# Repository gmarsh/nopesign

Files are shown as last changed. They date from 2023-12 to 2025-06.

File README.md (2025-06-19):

## NOPE sign design files  

**All files are (c) 2025, Gary Marsh (gmarsh @ github)
Released under a CC BY-SA V4.0 license.**

All files here are old, poorly organized and unsupported. Use at your own risk :)

You'll need the following tools:
 
- Microcontroller code:
-- STM32CubeIDE for editing/compiling the source code
-- STM32CubeProg for programming the sign over USB DFU
-- Both of the above are available free from ST Microelectronics (http://www.st.com)
- Schematic and PCB design: Kicad (http://www.kicad.org)
- 3D design: OpenSCAD (http://openscad.org)

Directory contents:
- /3d_design/ = STL files for sign
- /3d_design/openscad = OpenSCAD source code for generating the STL files. The code also generates a few SVG files (board outline, etc) to be used in Kicad.
- /kicad/ = Kicad project for the sign electronics
- /kicad/gerbers/ = Gerber files ready to order
- /kicad/production/ = JLCPCB files needed to do a production run. Not all parts are guaranteed to be in stock.
- /software/ = Source code for the STM32 microcontroller.

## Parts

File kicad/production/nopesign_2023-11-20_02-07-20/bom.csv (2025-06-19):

Designator | Footprint | Quantity | Value | LCSC Part #
C1, C10, C11, C12, C13, C14, C15, C16, C17, C18, C19, C2, C20, C21, C22, C23, C24, C25, C26, C27, C28, C29, C3, C30, C34, C35, C37, C38, C39, C4, C40, C41, C42, C43, C44, C45, C46, C47, C48, C49, C5, C50, C51, C52, C53, C54, C55, C56, C57, C58, C59, C6, C60, C61, C62, C63, C64, C65, C66, C67, C68, C69, C7, C70, C71, C8, C9 | 0603 | 67 | 0.1u | C14663
C31, C32, C33 | 0603 | 3 | 1000p | C1588
C36, C72 | 0805 | 2 | 1u | C28323
D1, D10, D11, D12, D13, D14, D15, D16, D17, D18, D19, D2, D20, D21, D22, D23, D24, D25, D26, D27, D28, D29, D3, D30, D31, D32, D33, D34, D35, D36, D37, D38, D39, D4, D40, D41, D42, D43, D44, D45, D46, D47, D48, D49, D5, D50, D51, D52, D53, D54, D55, D56, D57, D58, D59, D6, D60, D61, D62, D63, D64, D65, D7, D8, D9 | LED_WS2812B_PLCC4_5.0x5.0mm_P3.2mm | 65 | WS2812B | C2843785
FB1 | 0805 | 1 | 100Z | C1015
J1 | USB_C_Receptacle_HRO_TYPE-C-31-M-12 | 1 | USB_C_Receptacle_USB2.0 | C165948
R1 | 0603 | 1 | 1M | C22935
R2, R3 | 0603 | 2 | 5.1k | C23186
SW1 | SW_Tactile_SPST_Angled_PTS645Vx83-2LFS | 1 | DIM | C285530
SW2 | SW_Tactile_SPST_Angled_PTS645Vx83-2LFS | 1 | COLOR | C285530
SW3 | SW_Tactile_SPST_Angled_PTS645Vx83-2LFS | 1 | MODE | C285530
U1 | TSSOP-20_4.4x6.5mm_P0.65mm | 1 | STM32F042F6Px | C2969989
U2 | SOT-23-3 | 1 | XC6206PxxxMR | C5446
U3 | SOT-353_SC-70-5 | 1 | 74AHCT1G125 | C151417

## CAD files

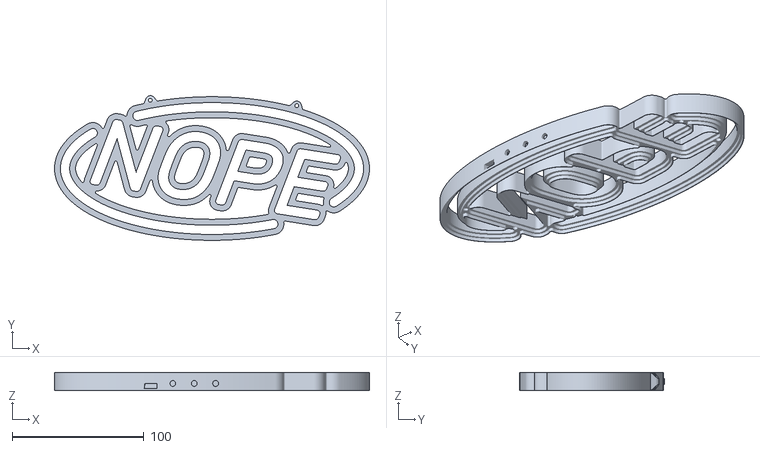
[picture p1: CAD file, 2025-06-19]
3D_design/nopesign_frame.stl
239.0 x 109.8 x 14.0

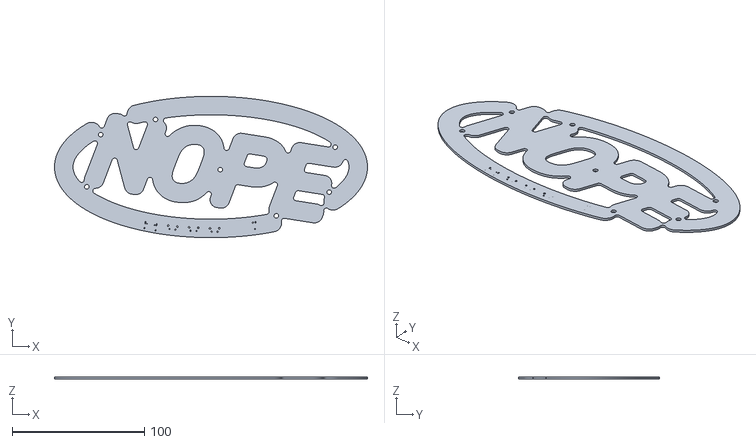
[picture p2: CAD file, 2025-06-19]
3D_design/openscad/nope_pcb.stl
237.0 x 107.0 x 1.58

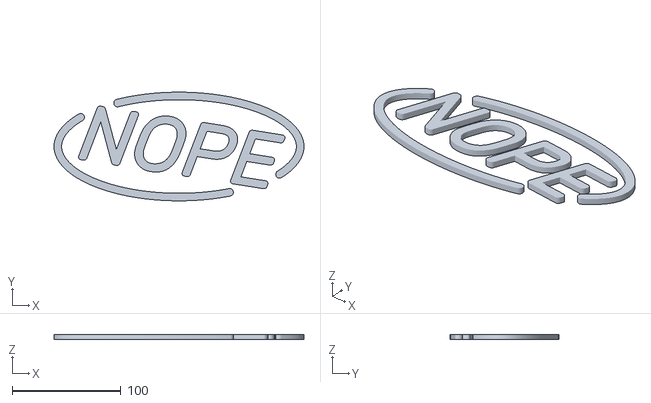
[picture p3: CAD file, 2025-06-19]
3D_design/nopesign_logo.stl
230.0 x 100.0 x 4.80

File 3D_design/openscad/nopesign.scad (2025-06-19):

/* 

nope sign SCAD file
(c) 2025, Gary Marsh, github.com/gmarsh
CC BY-SA V4.0 license

This code is a mess, but hopefully decipherable. Feel free to clean it up and throw it back at the github if you hate it.

Workflow for making a new sign:

(1) Make logo_2d() point at a SVG for a new logo.
(2) preview quick_preview_3d(), you'll probably need to mess with the positive/negative offsets in frame_2d() for a good looking outline.
(3) preview pcb_2d() and make sure it looks sane, then export it as a SVG. This is the PCB outline you want.
(4) Pull the SVG into Inkscape, disable fills, save it again as a SVG and import it into Kicad as the board outline layer.
(5) Do the same process for pcb_part_clearance_2d() and logo_2d() and bring those into Kicad on reference layers to guide part placement. 
(6) Do electronics nerd shit
(7) Export STEP files from Kicad for the PCB and parts, convert these to STLs, then update pcb_preview() to point at these files.
(8) Come up with all new cutouts in frame_3d() for buttons and switches and everything else. Confirm no interference by intersection()-ing pcb_preview() and frame_3d()/logo_3d().
(9) Once everything looks good, print frame_3d() and logo_3d() together to make your sign.

*/

// MAIN OUTPUTS

// uncomment for the frame (black plastic) part
color("#3F3F3F") frame_3d();
// uncomment for the logo (clear/opaque plastic) part
color("cyan",0.3) logo_3d();

// KICAD OUTPUTS

// board outline
//pcb_outline_2d();
// logo, for figuring out where to place LEDs etc on the board
//logo_2d();
// part clearance, don't place parts outside this area
//pcb_part_clearance_2d();


// OTHER OUTPUTS

// quick 3D preview for adjusting stuff. Doesn't have PCB or switch cutouts or anything, but renders quick.
//quick_3d_preview();
// PCB preview
//pcb_preview();



// first bit of configuration

// height of plastic above PCB top surface
main_height = 12;
// depth of plastic beside/behind PCB, make sure is >= PCB thickness (typically 1.6mm)
// total sign thicknness is main_height + back_depth
back_depth = 2;

// thickness of clear part. Thinner less light attention, thicker stronger and better diffusion.
logo_thickness = 4.8;
// how much smaller PCB is than the frame
pcb_offset = -1;
// gap between PCB outline and where it goes in
pcb_edge_clearance = 0.2;

// extra PCB clearance around the logo for parts etc
pcb_part_clearance_offset = 2;
pcb_part_clearance_height = 2;


module logo_3d() {
    difference() {
        translate([0,0,main_height]) mirror([0,0,1]) linear_extrude(height=logo_thickness) logo_2d();
        switch_cutouts();
    }
}



module frame_3d() {

    difference() {
    
        // main frame blank w/hangers added
        union() {
            translate([0,0,-back_depth]) linear_extrude(height=main_height + back_depth,convexity=5) difference() { frame_2d(); logo_2d(); }
            mounts();
        }
        
        // PCB cutout
        mirror([0,0,1]) linear_extrude(height=back_depth+1) offset(r=pcb_offset+pcb_edge_clearance) frame_2d();
        // PCB part clearance, 2mm above PCB, which clears most parts
        translate([0,0,-1]) linear_extrude(height=pcb_part_clearance_height+1) offset(r=pcb_part_clearance_offset) logo_2d();
        // PCB mounting holes
        pcb_holes();
        // USB cutout
        usb_cutout();
        // switch cutouts
        switch_cutouts();
        
    }
}

// string hangey dangleys
module mounts() {
    translate([-46.8,51.8,0]) rotate([0,0,10.5]) mount();
    translate([64.3,47.7,0])  rotate([0,0,-15.75]) mount();
}

module mount() {
    od = 7; id = 3;
    dx = 5.5; dy = 3;
    
    difference() {
        translate([0,0,-back_depth]) linear_extrude(height=main_height+back_depth,convexity=5) difference() {
            hull() {
                circle(d=od,$fn=32);
                translate([-dx,-dy]) circle(d=1,$fn=32);
                translate([dx,-dy]) circle(d=1,$fn=32);
            }
            circle(d=id,$fn=32);
        }
        
        translate([0,-id/2,main_height])  rotate([-45,0,0]) linear_extrude(height=10) square([3*od,3*od],center=true);
        translate([0,-id/2,-back_depth])  mirror([0,0,1]) rotate([-45,0,0]) linear_extrude(height=10) square([3*od,3*od],center=true);
    }
}


// difference between kicad coordinates and openscad coordinates, used in a bunch of functions below
part_dx = -150;
part_dy = 85;

module pcb_holes() {
    nudge = 0.1;
    // hole depth and diameter
    hole_depth = main_height - 2;
    hole_dia = 3.3;
    
    translate([0,0,-nudge]) linear_extrude(height=hole_depth+nudge) union() { 
        translate([66.5+part_dx,-60.5+part_dy]) circle(d=hole_dia,$fn=32);
        translate([56+part_dx,-100+part_dy]) circle(d=hole_dia,$fn=32);
        translate([108+part_dx,-49+part_dy]) circle(d=hole_dia,$fn=32);
        translate([157+part_dx,-87+part_dy]) circle(d=hole_dia,$fn=32);
        translate([199.5+part_dx,-122+part_dy]) circle(d=hole_dia,$fn=32);
        translate([239.5+part_dx,-104+part_dy]) circle(d=hole_dia,$fn=32);
        translate([244+part_dx,-70+part_dy]) circle(d=hole_dia,$fn=32);
    }
}

module usb_cutout() {
    // USB cutout
    usb_x = 104; usb_y = -131;
    usb_angle = -10.5;
    translate([0,0,-0.5]) linear_extrude(height=4) translate([usb_x+part_dx,usb_y+part_dy]) rotate(usb_angle) square([10,10],center=true);
}

// switch cutouts

module switch_cutouts() {
    switch_x = [123,139,155];
    switch_y = [-132.5,-133.5,-134];
    switch_angle = [174,177,180];
    
    for (i=[0:2]) {
        translate([switch_x[i]+part_dx,switch_y[i]+part_dy,0])
        rotate([0,0,switch_angle[i]]) switch_cutout();
    }
}

module switch_cutout() {
    translate([2.25,0,0]) union() {
        translate([0,0,-0.5]) linear_extrude(height=7.5) square([8,6.5],center=true);
        translate([0,0,3.5]) rotate([-90,0,0]) cylinder(d=4.5,$fn=32,h=10);
    }    
}




// quick 3D preview for checking stuff without rendering whole sign

module quick_3d_preview() {

    // mounts / string hangeys
    //color("#3F3F3F") mounts();
    // frame
    color("#3F3F3F") translate([0,0,-back_depth]) linear_extrude(height=main_height+back_depth) difference() { frame_2d(); logo_2d(); };
    // text
    color("#FFBFBF") translate([0,0,main_height]) mirror([0,0,1]) linear_extrude(height=logo_thickness) logo_2d();
}


// PCB preview for test fitment using STLs generated from Kicad

module pcb_preview() {
    union() {
        color("green") translate([-150,85,-1.6]) import("nope_pcb.stl",convexity=5);
        color("red") translate([-150,85,-1.6]) import("nope_pcb_partsonly.stl",convexity=5);
    }
}


module pcb_outline_2d() {
    offset(r=pcb_offset) frame_2d();
}

module pcb_part_clearance_2d() {
    offset(r=pcb_part_clearance_offset) logo_2d();
}

// frame: offset from logo

module frame_2d() {
    offset(r=-1,$fn=60) offset(r=5.5,$fn=60) logo_2d();
}

module logo_2d() {
    translate([-115.0,-150]) import("logo.svg");
}    

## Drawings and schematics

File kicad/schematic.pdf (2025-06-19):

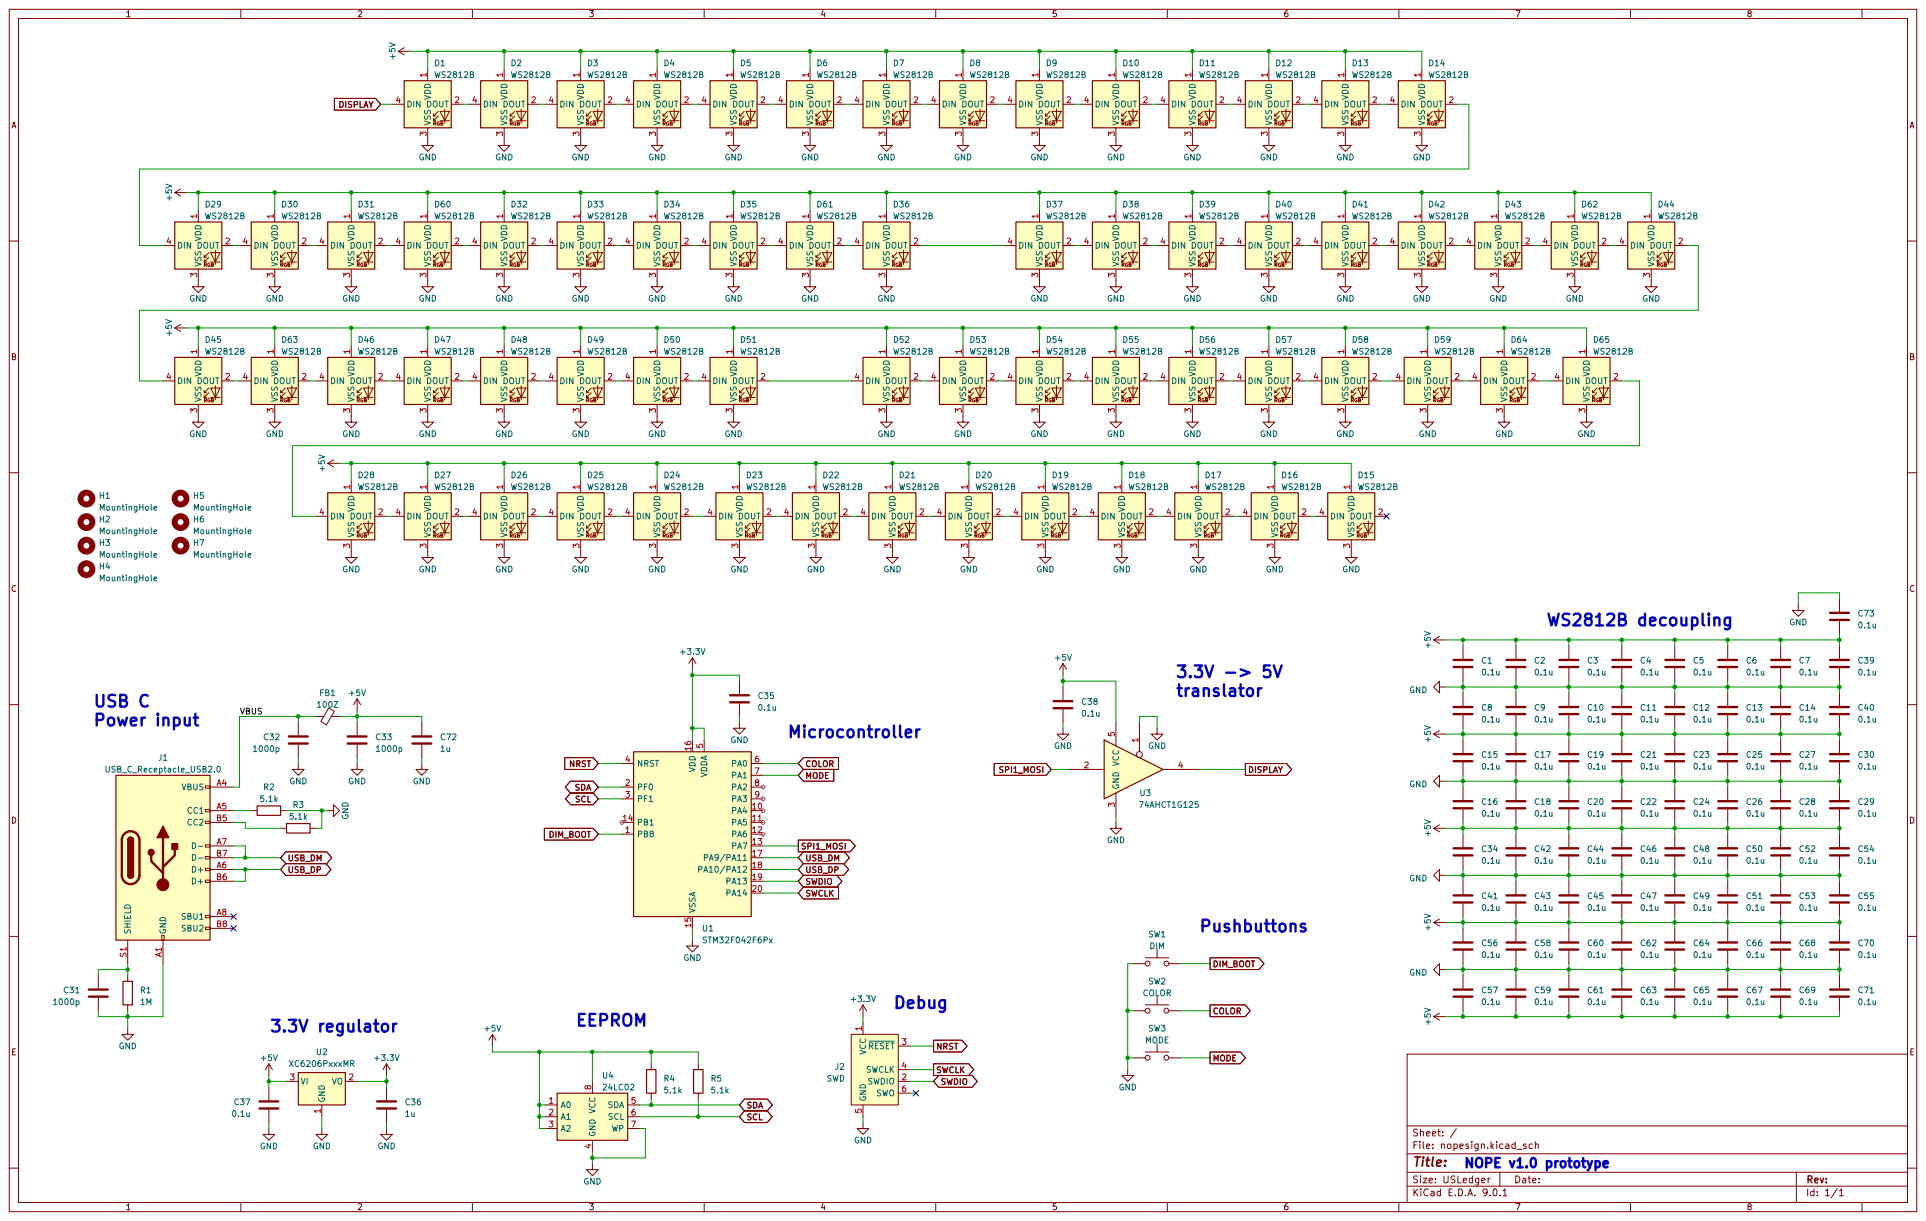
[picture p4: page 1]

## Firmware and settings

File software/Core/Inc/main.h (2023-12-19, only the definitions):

#define DIM_Pin GPIO_PIN_8
#define DIM_GPIO_Port GPIOB
#define COLOR_Pin GPIO_PIN_0
#define COLOR_GPIO_Port GPIOA
#define MODE_Pin GPIO_PIN_1
#define MODE_GPIO_Port GPIOA

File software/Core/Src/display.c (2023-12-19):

/*
 * display.c
 *
 *  Created on: Dec 10, 2023
 *      Author: Gary
 */

#include <stdint.h>
#include <stdbool.h>
#include "display.h"
#include "main.h"
#include "dfu_jump.h"
#include "eeprom.h"
#include <stm32f0xx_hal.h>

// also defined in modes_colors.c, make sure values match
#define PIXEL_COUNT 65

// GPIO defines
#define GPIO_DIM_PUSHED		(HAL_GPIO_ReadPin(DIM_GPIO_Port, DIM_Pin) == 0)
#define GPIO_MODE_PUSHED	(HAL_GPIO_ReadPin(MODE_GPIO_Port,MODE_Pin) == 0)
#define GPIO_COLOR_PUSHED	(HAL_GPIO_ReadPin(COLOR_GPIO_Port,COLOR_Pin) == 0)

// timings
#define BUTTON_DEBOUNCE_COUNT 3
// time to wait before writing new mode/color/dim to EEPROM
#define EEPROM_WRITE_DELAY 120
// amount of time to hold dim button to jump to DFU
#define DIM_DFU_HOLD 60


// === variables/buffers ===

// peripheral handles from HAL
extern SPI_HandleTypeDef hspi1;
extern DMA_HandleTypeDef hdma1;
extern TIM_HandleTypeDef htim14;

// lookup table for dim values
// 0x80 = maximum LED brightness
#define DIM_COUNT 6
const uint8_t dim_lut[] = { 0x04, 0x08, 0x10, 0x20, 0x40, 0x80 };

// "timer IRQ fired" flag
volatile bool timer_flag = false;

// configuration structure
// read/written from EEPROM
struct config_struct config;

// display state, holds data between display_update() calls
struct state_struct state;

// SPI output buffer
#define RESET_WORDS 2
#define DISPLAY_OUTPUT_BUFFER_SIZE (RESET_WORDS + (PIXEL_COUNT * 6))
uint16_t display_output_buffer[DISPLAY_OUTPUT_BUFFER_SIZE];


// == FUNCTIONS ==

// display timer callback

void HAL_TIM_PeriodElapsedCallback(TIM_HandleTypeDef *htim) {
	if (htim->Instance == htim14.Instance) {
		timer_flag = true;
	}
}

// display code initialization

void display_init(void) {

	// zero screen
	display_zero(display_output_buffer);

	// read config structure from EEPROM
	eeprom_read((uint8_t *) &config, 0, sizeof(config));

	// check dim value is sane, zero it if it isn't
	// mode code is responsible for validating modes/colors
	if (config.dim >= DIM_COUNT) config.dim = 0;

	// start 60hz timer interrupt
	HAL_TIM_Base_Start_IT(&htim14);
}


/*
 * bool display_update(*fb, frames);
 *
 * writes *fb to the display, then sleeps for 'delay' frames while doing button debouncing and handling.
 *
 * exits early and returns true if the mode or color changed, necessitating restarting the animation.
 * If this happened, state.color_push_edge and state.mode_push_edge can be checked by the mode code.
 *
 */

bool display_update(uint32_t *fb, int delay) {

	if (delay == 0) delay++;

	bool display_write_flag = true;

	while(delay--) {

		// sleep until next ISR
		while(!timer_flag) {
			HAL_SuspendTick();
			HAL_PWR_EnterSLEEPMode(PWR_MAINREGULATOR_ON, PWR_SLEEPENTRY_WFI);
			HAL_ResumeTick();
		}
		timer_flag = false;

		// update display if requested
		if (display_write_flag) {
			display_load_tx_buffer(fb,display_output_buffer,dim_lut[config.dim]);
			display_write_flag = false;
		}

		// handle buttons, decide what to do
		if (GPIO_DIM_PUSHED) {
			if (state.dim_debounce_counter < BUTTON_DEBOUNCE_COUNT) {
				state.dim_debounce_counter++;
				if (state.dim_debounce_counter == BUTTON_DEBOUNCE_COUNT) {
					if (!state.dim_pushed) {
						config.dim++;
						if (config.dim == DIM_COUNT) config.dim = 0;
						display_write_flag = true;
						state.eeprom_write_flag = true;
					}
					state.dim_pushed = true;
				}
			} else {
				if (++state.dim_dfu_hold_counter >= DIM_DFU_HOLD) goto dfu_jump;
			}
		} else {
			state.dim_dfu_hold_counter = 0;
			if (state.dim_debounce_counter > 0) {
				state.dim_debounce_counter--;
				if (state.dim_debounce_counter == 0) state.dim_pushed = false;
			}
		}

		if (GPIO_COLOR_PUSHED) {
			if (state.color_debounce_counter < BUTTON_DEBOUNCE_COUNT) {
				state.color_debounce_counter++;
				if (state.color_debounce_counter == BUTTON_DEBOUNCE_COUNT) {
					if (!state.color_pushed) {
						state.color_push_edge = true;
						state.color_pushed = true;
						state.abort_flag = true;
					}
				}
			}
		} else {
			if (state.color_debounce_counter > 0) {
				state.color_debounce_counter--;
				if (state.color_debounce_counter == 0) state.color_pushed = false;
			}
		}

		if (GPIO_MODE_PUSHED) {
			if (state.mode_debounce_counter < BUTTON_DEBOUNCE_COUNT) {
				state.mode_debounce_counter++;
				if (state.mode_debounce_counter == BUTTON_DEBOUNCE_COUNT) {
					if (!state.mode_pushed) {
						state.mode_push_edge = true;
						state.mode_pushed = true;
						state.abort_flag = true;
					}
				}
			}
		} else {
			if (state.mode_debounce_counter > 0) {
				state.mode_debounce_counter--;
				if (state.mode_debounce_counter == 0) state.mode_pushed = false;
			}
		}

		// handle configuration write to EEPROM
		if (state.eeprom_write_flag) {
			state.eeprom_write_flag = false;
			state.eeprom_write_timeout = EEPROM_WRITE_DELAY;
		} else if (state.eeprom_write_timeout) {
			if (--state.eeprom_write_timeout == 0) {
				eeprom_write((uint8_t *) &config, 0, sizeof(config));
			}
		}

		if (state.abort_flag) return true;
	}

	return state.abort_flag;


	dfu_jump:

		display_zero(display_output_buffer);
		dfu_jump();

		while(1);

}


/*
 * display_load_tx_buffer(*src, *dest, dimlevel)
 *
 * *src = source framebuffer. Format is 32 bit 0xddRRGGBB.
 * *dest = SPI transmit buffer
 * dimlevel = global dim level
 *
 */

// nibble lookup table for assembling SPI stream - requires 3Mbit/sec SPI data rate to meet timing spec
const uint16_t disp_spi_lut[16] = {
	 0x8888, 0x888E, 0x88E8, 0x88EE, 0x8E88, 0x8E8E, 0x8EE8, 0x8EEE,
	 0xE888, 0xE88E, 0xE8E8, 0xE8EE, 0xEE88, 0xEE8E, 0xEEE8, 0xEEEE,
};
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

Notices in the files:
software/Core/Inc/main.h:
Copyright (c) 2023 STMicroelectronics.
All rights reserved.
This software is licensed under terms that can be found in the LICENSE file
